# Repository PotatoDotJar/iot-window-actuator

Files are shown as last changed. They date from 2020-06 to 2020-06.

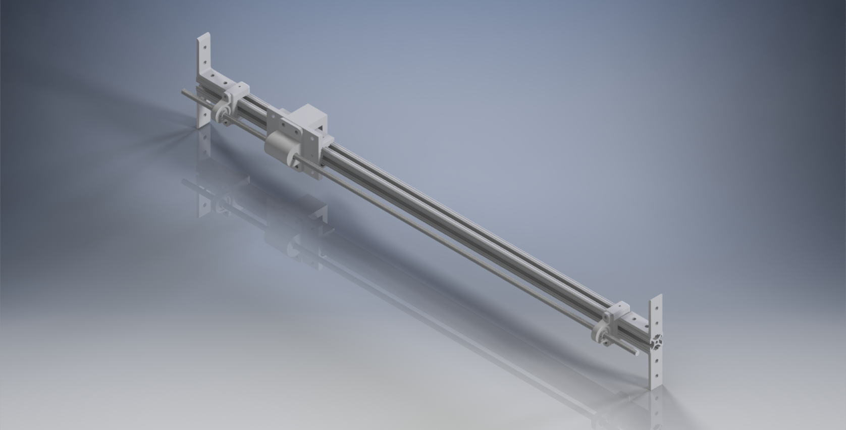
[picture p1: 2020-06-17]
MechanicalDesigns/CAD_Render_Full_Assembly.png

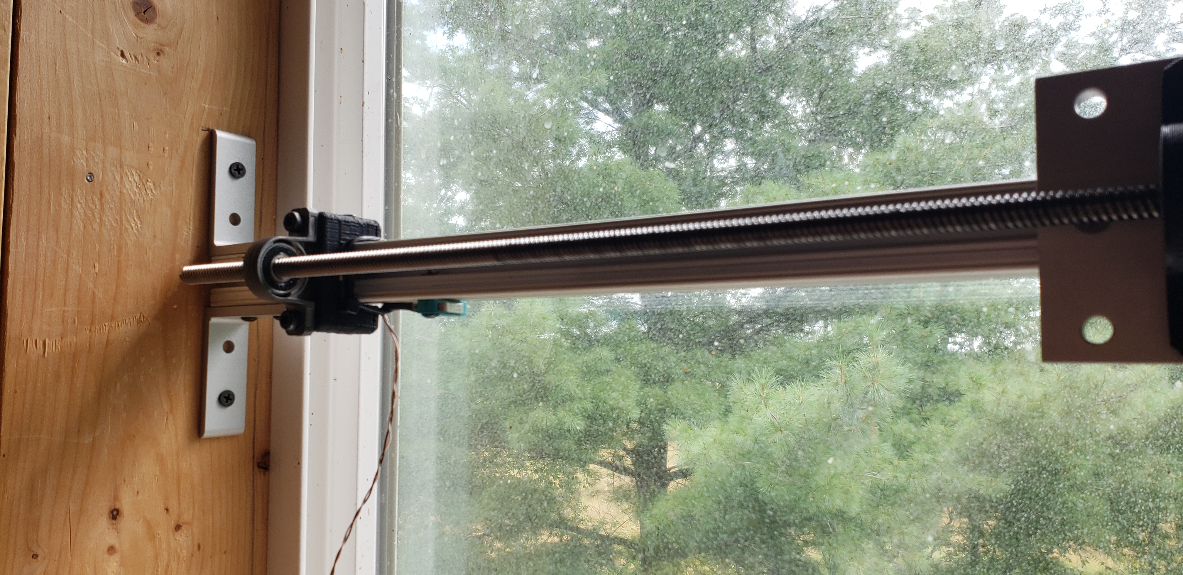
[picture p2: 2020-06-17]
MechanicalDesigns/20190813_112358.jpg

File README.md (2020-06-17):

# iot-window-actuator
ESP32 Firmware for a IOT window actuator I built for a client. Note: This is not the whole project, for security reasons the rest of the project remains private.

# The Project
These devices are used in a wedding barn venue to remotely open and close windows in the rafters as well as monitor the air temperature. I have worked on this project on the side for over two years while going to school and working as an intern software developer for Fynydd LLC. This project has tested my knowledge on various subjects both in software development and outside of software such as electrical and mechanical engineering. I have strengthened my knowledge on these subjects substantially through my many mistakes and iterations in my designs. With my CAD class in high school and my self-taught hobbyist electronics skills, I managed to make a fully functional IOT sliding window opener using various 8020 parts, 3D printed parts I designed, and circuit boards which were designed by me using EasyEDA and manufactured though JLC PCB (see images in the Electrical folder for designs).

# Folder Structure
### ControllerFirmwareV4/
ESP32 Microcontroller firmware developed in C++ using PlatformIO in VS Code.

### ElectricalDesigns/
Electrical schematics and circuit board designs.

### MechanicalDesigns/
CAD renderings and designs.

### VeryOldControllerFirmware/
This is the super old firmware I started with on this project. It was very buggy and had a lot of issues. I only added it to compare how far I have come with my C/C++ skills.

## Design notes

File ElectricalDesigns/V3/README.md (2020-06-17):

# V3
This design was a winner! With some minor changes, most notably the led pin change, this board was the final version and is currently being used in production. One issue I had to fix was removing the reset pin, TX pin, and RX pins from the remote. They caused unwanted resets and issues with the LED data writing.

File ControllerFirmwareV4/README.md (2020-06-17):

# Controller Firmware
The firmware changed A LOT over the course of this project and I definitely improved my C/C++ skills. There are way too many changes for me to remember so this is just a snapshot of the current production firmware I recently re-wrote using what I learned about designing programs using C++. Most of everything is static since there is only ever once instance of every class. This also makes it easier for the classes to depend on each other. I am sure there is a better way of organizing this, I just wanted to get this project done in a timely manner.

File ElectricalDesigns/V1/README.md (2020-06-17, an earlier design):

# V1
This hand-made board was one of my many early prototype boards. It uses a full ESP32 development board and suffered from poor power delivery to the microcontroller causing weird issues such as the WiFi going out randomly, the web server stops responding after the first request, Bluetooth BLE loosing communication, etc.

While this was an early prototype, it established the base circuit design.

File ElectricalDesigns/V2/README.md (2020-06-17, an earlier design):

# V2
This board was also problematic as I incorrectly routed some of the traces for the remote. The board also used a 5V voltage regulator that could not supply enough current to the ESP32 causing the issues mentioned in the V1 README. Those issues related to WiFi and network connectivity lead to hours of research and lots of hair-loss... Asside from the networking issues, this board used the boot GPIO as the LED data output causing some issues with the controller going into firmware upload mode when reset while the led was being changed.

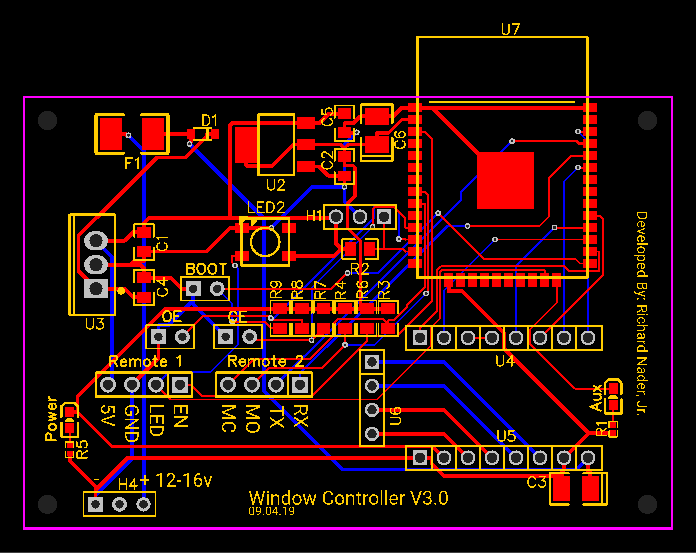
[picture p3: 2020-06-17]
ElectricalDesigns/V3/PCB_Main_PCB_2020-06-16_23-12-46.png

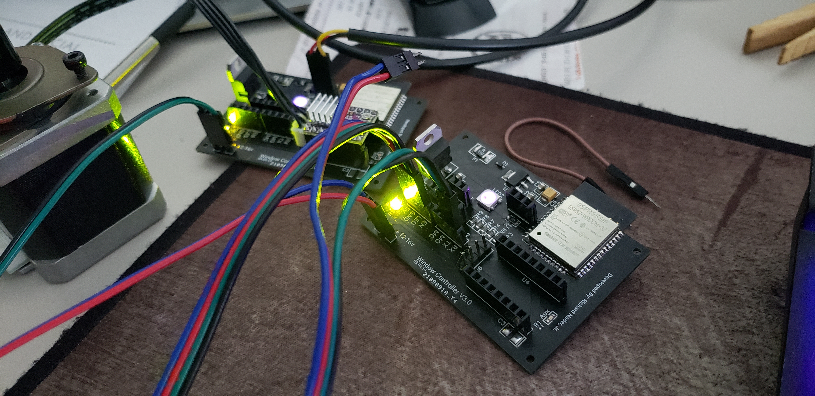
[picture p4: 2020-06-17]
ElectricalDesigns/V3/FinalPrototypeV5.jpg

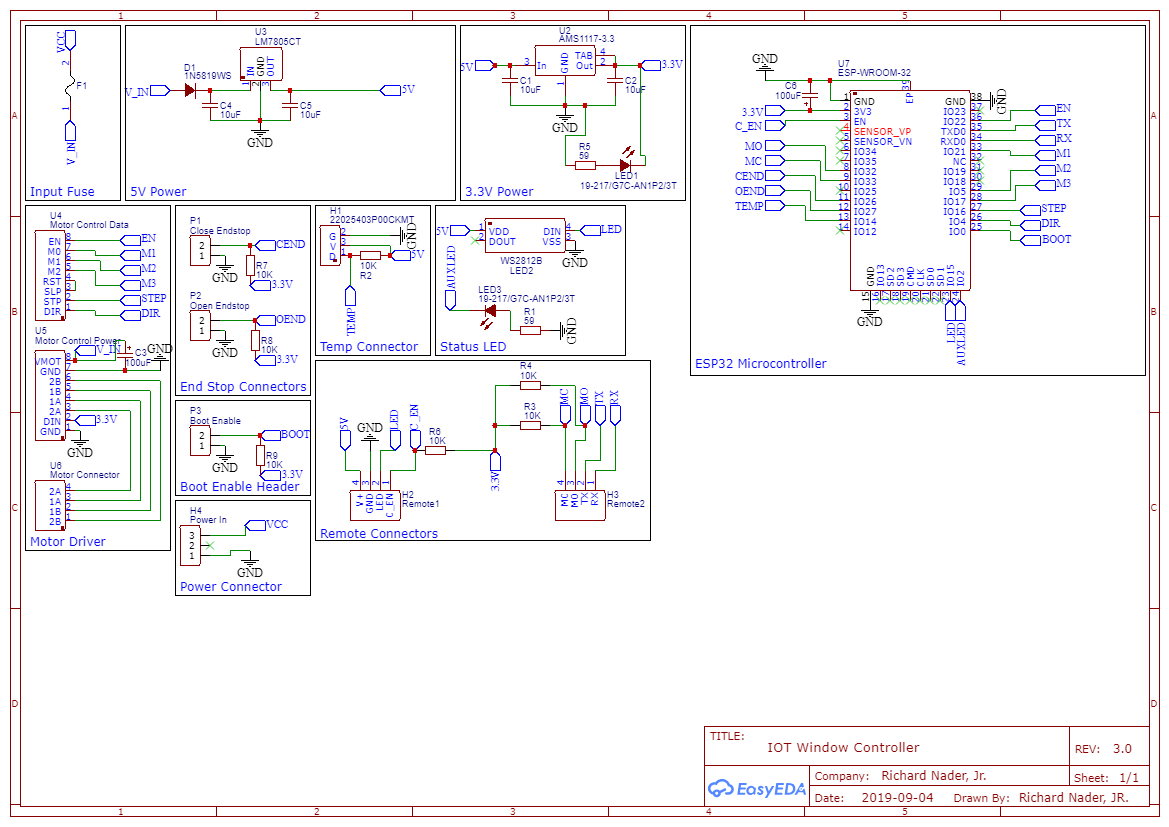
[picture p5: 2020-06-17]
ElectricalDesigns/V3/Schematic_Window Controller 3.0_2020-06-16_23-11-40.png

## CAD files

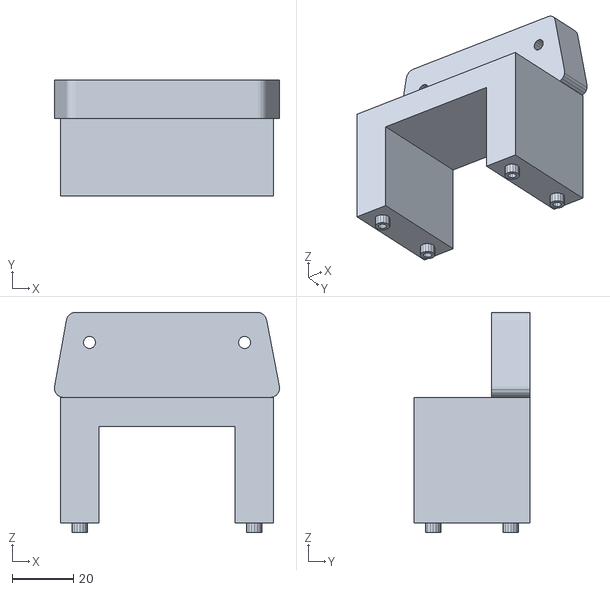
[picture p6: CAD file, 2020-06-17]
MechanicalDesigns/WindowBracket.stl
73.7 x 38.1 x 72.2

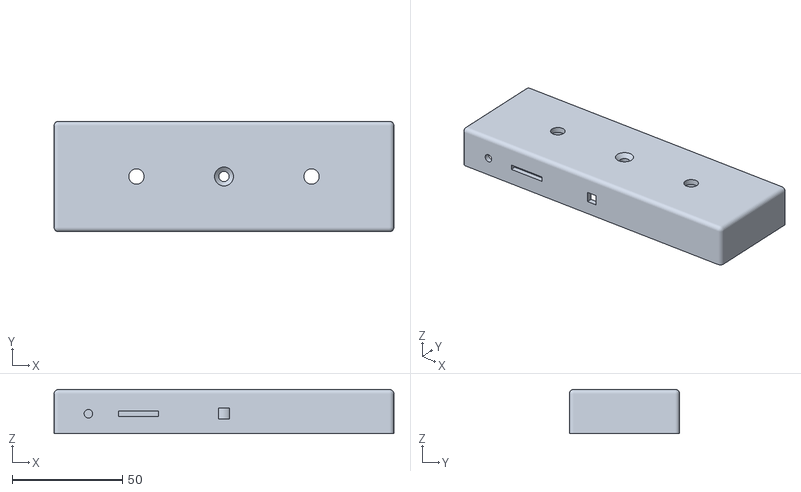
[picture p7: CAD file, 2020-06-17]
MechanicalDesigns/WallRemote-V3.stl
154.0 x 50.0 x 20.0

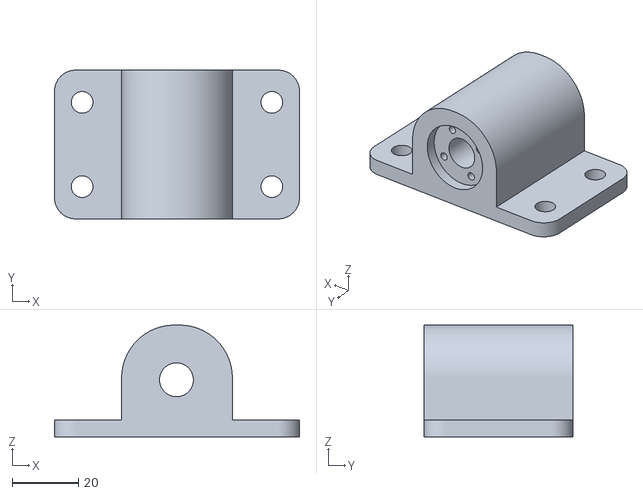
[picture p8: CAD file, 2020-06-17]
MechanicalDesigns/ShaftToRailCoupler.stl
73.8 x 44.8 x 33.7

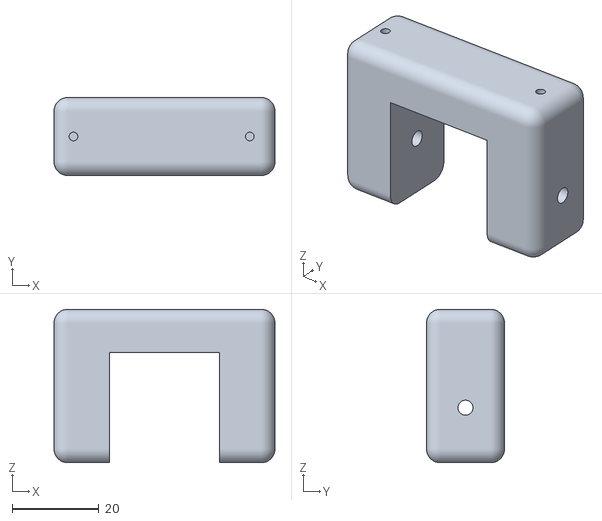
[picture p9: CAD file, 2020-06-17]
MechanicalDesigns/PillowBearingBracket.stl
51.0 x 18.0 x 35.4

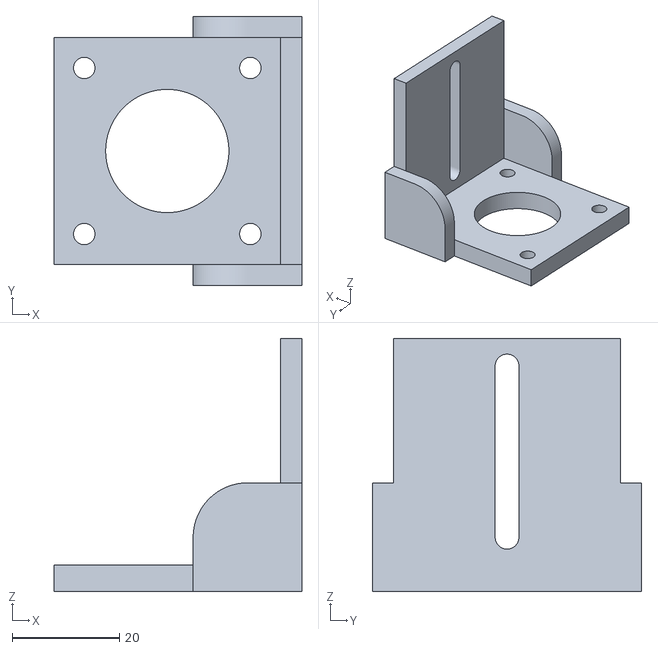
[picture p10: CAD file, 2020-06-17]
MechanicalDesigns/MotorBracket.stl
46.3 x 50.3 x 47.3

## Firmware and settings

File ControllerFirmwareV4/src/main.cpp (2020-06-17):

#include <Arduino.h>

// Classes
#include "shared.h"
#include "led_control.h"

// Temp feature
#ifdef ENABLE_TEMP_FEATURE
#include "temperature_control.h"
#endif

#include "wifi_control.h"
#include "motor_control.h"
#include "utility_functions.h"
#include "ota_control.h"
#include "remote_control.h"
#include "mqtt_control.h"

void setup()
{
	// Setup logging
	String welcomeMessage = "Connected to " + String(CLIENT_ID) + "\r\nOpen=O, Close=C, Stop=S, Check Error=E, Clear Error=X, WiFiSignal=W, Restart=R, Cur Temp=T\r\n";
	LOG.setWelcomeMsg((char *)welcomeMessage.c_str());
	LOG.begin(115200);

	LedControl::begin();

#ifdef ENABLE_TEMP_FEATURE
	TemparatureControl::begin();
#endif

	WiFiControl::begin();
	MotorControl::begin();
	Utilities::begin();
	OtaHandler::begin();
	RemoteControl::begin();
	MqttControl::begin();
}

void loop()
{
	LedControl::handle();

#ifdef ENABLE_TEMP_FEATURE
	TemparatureControl::handle();
#endif

	WiFiControl::handle();
	MotorControl::handle();
	Utilities::handle();
	OtaHandler::handle();
	RemoteControl::handle();
	MqttControl::handle();


	// Don't handle Telnet logging while motor is running,
    // this will cause the motor to stall under load.
	if (!MotorControl::isMotorMoving())
	{
		LOG.handle();
	}

	// Handle Telnet commands for testing
	if (LOG.available() > 0)
	{
		char command = LOG.read();

		if (command == 'O')
		{
			MotorControl::setRequestedMotorState(MotorState::OPENING);
		}
		else if (command == 'C')
		{
			MotorControl::setRequestedMotorState(MotorState::CLOSING);
		}
		else if (command == 'S')
		{
			MotorControl::setRequestedMotorState(MotorState::STOPPED);
		}
		else if (command == 'E')
		{
			if (LedControl::hasErrorOccured())
			{
				LOG.print("Last error code is ");
				LOG.println(LedControl::getErrorCodeString(LedControl::getErrorCode()));
			}
			else
			{
				LOG.println("No recent errors have occured.");
			}
		}
		else if (command == 'X')
		{
			LOG.println("Clearing errors.");
			LedControl::setErrorHasOccured(false);
			LedControl::setBaseStatus();
		}
		else if (command == 'W')
		{
			LOG.print("WiFi Signal Strength is ");
			LOG.println(WiFi.RSSI());
		}
		else if (command == 'R')
		{
			Utilities::restartController();
		}
		else if (command == 'T')
		{
#ifdef ENABLE_TEMP_FEATURE
			LOG.print("Temperature F: ");
			LOG.println(TemparatureControl::getCurrentTempF());
#else
			LOG.println("Temp feature not supported on this controller.");
#endif
		}
	}
}

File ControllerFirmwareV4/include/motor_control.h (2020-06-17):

#pragma once
#include "shared.h"
#include "led_control.h"

enum class WindowState : uint8_t
{
    NONE = 0,
    CLOSING = 1,
    OPENING = 2,
    CLOSED = 3,
    OPEN = 4,
    CLOSING_ERROR = 5,
    OPENING_ERROR = 6,
    UPDATING = 7,
    UPDATE_COMPLETE = 8,
    RESTARTING = 9
};

enum class MotorState : uint8_t
{
    STOPPED = 0,
    CLOSING = 1,
    OPENING = 2
};

class MotorControl
{
private:
    static bool motorEnabled;
    static bool triggered;
    static unsigned long lastMovementStart;
    static MotorState requestedMotorState;
    static WindowState currentWindowState;

    static void InitialWindowSetup();
    static void HandleMotorState();
    static void enableStepper();            // Enable stepper power
    static void disableStepper();           // Disable stepper power
    static bool isOpenEndstopTriggered();   // Is the open endstop triggered
    static bool isClosedEndstopTriggered(); // Is the closed endstop triggered

    

public:
    static void begin();
    static void handle();

    static void (*onWindowStateChange)(WindowState *curWindowState);
    static void setWindowStateChangeCallback(void (*func)(WindowState *curWindowState));

    static bool isMotorMoving();
    static WindowState getCurrentWindowState();
    static MotorState getRequestedMotorState();
    static void setCurrentWindowState(WindowState newState);
    static void setRequestedMotorState(MotorState requestedState);
    static String getWindowStateString(WindowState state);
    static String getMotorStateString(MotorState state);
};


// Static member definitions
bool MotorControl::motorEnabled = false;
bool MotorControl::triggered = false;
unsigned long MotorControl::lastMovementStart = 0U;
MotorState MotorControl::requestedMotorState = MotorState::STOPPED;
WindowState MotorControl::currentWindowState = WindowState::NONE;

void (*MotorControl::onWindowStateChange)(WindowState *curWindowState) = NULL;

// Private methods
void MotorControl::InitialWindowSetup()
{
    if (isOpenEndstopTriggered())
    {
        setCurrentWindowState(WindowState::OPEN);
    }
    else if (isClosedEndstopTriggered())
    {
        setCurrentWindowState(WindowState::CLOSED);
    }
    else
    {
        if (AUTO_CLOSE_ON_STARTUP)
        {
            enableStepper();
            LOG.println("Initially closing window...");

            bool running = true;
            LedControl::setStatusLedColor(StatusColors::HOMING);
            lastMovementStart = millis();
            stepper.setSpeed(MOTOR_SPEED);
            while (running)
            {
                stepper.runSpeed();

                if (isClosedEndstopTriggered())
                {
                    stepper.stop();
                    LOG.println("Window initially closed.");
                    setCurrentWindowState(WindowState::CLOSED);
                    running = false;
                }

                if (millis() - lastMovementStart >= MOTOR_RUN_TIMEOUT)
                {
                    stepper.stop();
                    LOG.println("Endstop has not been reached yet, stopping. Check window.");
                    setCurrentWindowState(WindowState::CLOSING_ERROR);
                    running = false;
                }
            }

            disableStepper();
            LedControl::setBaseStatus();
        }
    }
}

void MotorControl::HandleMotorState()
{
    if (requestedMotorState == MotorState::CLOSING)
    {
        // Run this once
        if (!triggered)
        {
            enableStepper();
            LOG.println("Closing window...");
            setCurrentWindowState(WindowState::CLOSING);
            stepper.setSpeed(MOTOR_SPEED);
            LedControl::setStatusLedColor(StatusColors::CLOSING);
            LedControl::setLedDimTemp(false); // Temp disable led dimming
            lastMovementStart = millis();
            triggered = true;
        }

        // Runs while motor state is CLOSING
        stepper.runSpeed();

        // End
        if (isClosedEndstopTriggered())
        {
            LOG.println("Window closed.");
            setCurrentWindowState(WindowState::CLOSED);
            requestedMotorState = MotorState::STOPPED;
        }

        // End with error
        if (millis() - lastMovementStart >= MOTOR_RUN_TIMEOUT)
        {
            LOG.println("Endstop has not been reached yet, stopping. Check window.");
            LedControl::setErrorHasOccured(true, ErrorCode::MOTOR_ENDSTOP_ERROR);
            setCurrentWindowState(WindowState::CLOSING_ERROR);
            requestedMotorState = MotorState::STOPPED;
        }
    }
    else if (requestedMotorState == MotorState::OPENING)
    {
        // Run this once
        if (!triggered)
        {
            enableStepper();
            LOG.println("Opening window...");
            setCurrentWindowState(WindowState::OPENING);
            stepper.setSpeed(-MOTOR_SPEED);
            LedControl::setStatusLedColor(StatusColors::OPENING);
            LedControl::setLedDimTemp(false); // Temp disable led dimming
            lastMovementStart = millis();
            triggered = true;
        }

        // Runs while motor state is OPENING
        stepper.runSpeed();

        // End
        if (isOpenEndstopTriggered())
        {
            LOG.println("Window opened.");
            setCurrentWindowState(WindowState::OPEN);
            requestedMotorState = MotorState::STOPPED;
        }

        // End with error
        if (millis() - lastMovementStart >= MOTOR_RUN_TIMEOUT)
        {
            LOG.println("Endstop has not been reached yet, stopping. Check window.");
            LedControl::setErrorHasOccured(true, ErrorCode::MOTOR_ENDSTOP_ERROR);
            setCurrentWindowState(WindowState::OPENING_ERROR);
            requestedMotorState = MotorState::STOPPED;
        }
    }
    else
    {
        // If stopped or anything else
        if (triggered)
        {
            triggered = false;
            disableStepper();
            stepper.stop();
            
            if (currentWindowState != WindowState::CLOSED && currentWindowState != WindowState::OPEN && currentWindowState != WindowState::CLOSING_ERROR && currentWindowState != WindowState::OPENING_ERROR)
            {
                setCurrentWindowState(WindowState::NONE);
            }

            LedControl::setBaseStatus();
            LedControl::setLedDimTemp(true); // Re-enable led dimming
        }
    }
}

void MotorControl::enableStepper()
{
    digitalWrite(ENABLE_PIN, LOW);
    motorEnabled = true;
}

void MotorControl::disableStepper()
{
    digitalWrite(ENABLE_PIN, HIGH);
    motorEnabled = false;
}

bool MotorControl::isOpenEndstopTriggered()
{
    return !digitalRead(OPEN_ENDSTOP_PIN);
}

bool MotorControl::isClosedEndstopTriggered()
{
    return !digitalRead(CLOSE_ENDSTOP_PIN);
}
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

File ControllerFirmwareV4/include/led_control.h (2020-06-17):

#pragma once
#include "shared.h"

// Status color definitions
enum class StatusColors : uint8_t
{
    OPENING = 0,
    CLOSING = 1,
    HOMING = 2,
    WIFI_CONNECTED = 3,
    WIFI_DISCONNECTED = 4,
    MQTT_IS_CONNECTED = 5,
    MQTT_CONNNECTING = 6,
    UPDATE_START = 7,
    UPDATE_SUCCESS = 8,
    RESTARTING = 9,
    ERROR = 10,
    OFF = 11
};

// Error event definitions
enum class ErrorCode : uint8_t
{
    NONE = 0,
    MOTOR_ENDSTOP_ERROR = 1,
    UPDATE_ERROR = 2
};

class LedControl
{
private:
    static CRGB statusLedColor[1];

    // Led dimming state variables
    static bool enableLedDim;
    static bool tempLedDim;
    static bool requestLedDim;
    static bool ledDimmed;
    static unsigned long lastLEDWakeTime;
    static unsigned long lastLEDDimTime;

    // Error state variables
    static bool errorHasOccured;
    static ErrorCode errorCode;

public:
    // Methods
    static void setStatusLedColor(CRGB newColor, bool dimLed = true);
    static void setStatusLedColor(StatusColors newColor, bool dimLed = true);
    static CRGB getStatusLedColor();
    static void setBaseStatus();

    static void setLedDimTemp(bool shouldDim);

    static void setErrorHasOccured(bool hasErrorOccured, ErrorCode newErrorCode = ErrorCode::NONE);
    static bool hasErrorOccured();
    static ErrorCode getErrorCode();
    static String getErrorCodeString(ErrorCode errorCode);

    static void begin();
    static void handle();
};

// Static member definitions
CRGB LedControl::statusLedColor[1] = { CRGB::Black };
bool LedControl::enableLedDim = false;
bool LedControl::tempLedDim = false;
bool LedControl::requestLedDim = false;
bool LedControl::ledDimmed = false;
unsigned long LedControl::lastLEDWakeTime = 0U;
unsigned long LedControl::lastLEDDimTime = 0U;
bool LedControl::errorHasOccured = false;
ErrorCode LedControl::errorCode = ErrorCode::NONE;


// Public methods
void LedControl::setStatusLedColor(CRGB newColor, bool dimLed)
{
    statusLedColor[0] = newColor;
    FastLED.setBrightness(255);
    FastLED.show();

    requestLedDim = false;
    ledDimmed = false;

    if (dimLed)
    {
        enableLedDim = true;
        lastLEDWakeTime = millis();
    }
    else
    {
        enableLedDim = false;
    }
}

void LedControl::setStatusLedColor(StatusColors newColor, bool dimLed)
{

    switch (newColor)
    {
    case StatusColors::OPENING:
        statusLedColor[0] = CRGB::Green;
        break;
    case StatusColors::CLOSING:
        statusLedColor[0] = CRGB::Yellow;
        break;
    case StatusColors::HOMING:
        statusLedColor[0] = CRGB::Orange;
        break;
    case StatusColors::WIFI_CONNECTED:
        statusLedColor[0] = CRGB::Blue;
        break;
    case StatusColors::WIFI_DISCONNECTED:
        statusLedColor[0] = CRGB::Brown;
        break;
    case StatusColors::MQTT_IS_CONNECTED:
        statusLedColor[0] = CRGB::Purple;
        break;
    case StatusColors::MQTT_CONNNECTING:
        statusLedColor[0] = CRGB::Turquoise;
        break;
    case StatusColors::UPDATE_START:
        statusLedColor[0] = CRGB::GreenYellow;
        break;
    case StatusColors::UPDATE_SUCCESS:
        statusLedColor[0] = CRGB::DarkGreen;
        break;
    case StatusColors::RESTARTING:
        statusLedColor[0] = CRGB::GreenYellow;
        break;
    case StatusColors::ERROR:
        statusLedColor[0] = CRGB::IndianRed;
        break;
    case StatusColors::OFF:
        statusLedColor[0] = CRGB::Black;
        break;
    default:
        break;
    }

    setStatusLedColor(statusLedColor[0], dimLed);
}

CRGB LedControl::getStatusLedColor()
{
    return statusLedColor[0];
}

void LedControl::setBaseStatus()
{
    if (errorHasOccured)
    {
        setStatusLedColor(StatusColors::ERROR);
        return;
    }

    if (WiFi.status() == WL_CONNECTED)
    {
        if (mqttClient.connected())
        {
            setStatusLedColor(StatusColors::MQTT_IS_CONNECTED);
        }
        else
        {
            setStatusLedColor(StatusColors::WIFI_CONNECTED);
        }
    }
    else
    {
        setStatusLedColor(StatusColors::WIFI_DISCONNECTED);
    }
}

void LedControl::setLedDimTemp(bool shouldDim)
{
    tempLedDim = shouldDim;
}

void LedControl::setErrorHasOccured(bool hasErrorOccured, ErrorCode newErrorCode)
{
    errorHasOccured = hasErrorOccured;

    errorCode = newErrorCode;
}

bool LedControl::hasErrorOccured()
{
    return errorHasOccured;
}

ErrorCode LedControl::getErrorCode()
{
    return errorCode;
}

String LedControl::getErrorCodeString(ErrorCode errorCode)
{
    switch (errorCode)
    {
    case ErrorCode::NONE:
        return String("NONE");
        break;

    case ErrorCode::MOTOR_ENDSTOP_ERROR:
        return String("MOTOR_ENDSTOP_ERROR");
        break;

    case ErrorCode::UPDATE_ERROR:
        return String("UPDATE_ERROR");
        break;

    default:
        return String("UNKNOWN");
        break;
    }
}

void LedControl::begin()
{
    LOG.println("Setting up led control");

    // Init static variables
    enableLedDim = true;
    tempLedDim = true;
    requestLedDim = false;
    ledDimmed = false;

    errorHasOccured = false;

    FastLED.addLeds<WS2812B, RGB_LED_PIN, GRB>(statusLedColor, 1);
    FastLED.setBrightness(255);
    setStatusLedColor(StatusColors::OFF);
    FastLED.show(); // Write data to led
}

void LedControl::handle()
{
    if (enableLedDim && tempLedDim)
    {
        // Handle led dim timeout
        if (!ledDimmed && !requestLedDim)
        {
            // Wait for timeout to dim led
            if (millis() - lastLEDWakeTime >= LED_DIM_DELAY)
            {
                //LOG.println("LED Dim triggered");
                requestLedDim = true;
                lastLEDDimTime = millis();
            }
        }
        else
        {
            if (!ledDimmed)
            {
                // Non-blocking led dimming
                unsigned long timeDifference = millis() - lastLEDDimTime;
                uint8_t calculatedVal = map(timeDifference, 0, LED_DIM_SPEED, 255, 1);

                //LOG.printf("LED Dim Debug: dif=%i val=%i\r", timeDifference, calculatedVal);

                FastLED.setBrightness(calculatedVal);
                FastLED.show();

                if (timeDifference >= LED_DIM_SPEED)
                {
                    // Led Dim complete
                    //LOG.printf("\nLED Dim Complete!");
                    ledDimmed = true;
                    requestLedDim = false;
                    lastLEDDimTime = 0;
                }
            }
        }
    }
}
